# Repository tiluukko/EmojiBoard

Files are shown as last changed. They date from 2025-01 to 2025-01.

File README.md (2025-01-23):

# EmojiBoard
Emojiboard documentation &amp; build kit assets &amp; instructions

    LUX
    Emojiboard
    v2.0
    Luukkonen Timo
    1-22-2025

Device and Program Documentation

OVERVIEW

The hardware setup includes a Raspberry Pi (version 3 B v1.2) connected to:
    
        •	A 3x7 + 2x2 button matrix.
        •	NeoPixel LEDs (26 units).
        •	A buzzer (connected to GPIO pin 16).
        •	The program logs keypresses into a CSV file.

The program is implemented in Python and uses libraries such as RPi.GPIO, rpi_ws281x, and datetime. It starts automatically when the device boots using a cron job and saves keypresses to the file keypress_log.csv         located in the /home/emojikeyboard folder.
 

PROGRAM FUNCTIONALITY

NEOPIXEL LED CONTROL

Each button in the matrix is linked to a specific NeoPixel LED. When a button is pressed, its corresponding NeoPixel lights up green and returns to its default state once the button is released. NeoPixel 10 is programmatically set to remain off at all times and is not used in the program.

BUTTON MATRIX

The matrix is divided into two sections:

    1.	A 3x7 matrix.
    2.	A 2x2 matrix.

The buttons are assigned the following functions:

    •	BACKSPACE: Clears the keypresses in the current session.
    •	RETURN: Saves the current session data and starts a new session.
    •	Other buttons: Add the pressed key to the current session.
    •	Key to Emojis conversion table attached to this document.

KEYPRESS LOGGING

The program logs each session in the following format:

    •	A username (randomly generated combination of an adjective, animal, and unique code).
    •	Keypresses.
    •	A timestamp of when the session is saved.

The data is stored in the file keypress_log.csv.

AUTOMATIC PROGRAM STARTUP

The program is configured to run automatically on device boot using a cron job. Add the following line to the user’s crontab file by running crontab -e:

        @reboot python3 /home/emojikeyboard/keyboard-140.py

INSTRUCTIONS FOR COPYING KEYPRESS_LOG.CSV TO A USB STICK

    1.    Connect HDMI display and a regular keyboard to the Emojiboard.
  	2.    Connect power cable.
    3.    Insert the USB stick into the Raspberry Pi.
    4.    Identify the USB stick’s mount point using the command: 
            lsblk
          
          The stick is typically listed as /dev/sda1.
    
    5.    Mount the USB stick using the command (assuming it is /dev/sda1): 
            sudo mount /dev/sda1 /mnt

    6.    Copy the log file to the USB stick:     
        cp /home/emojikeyboard/keypress_log.csv /mnt

    7.    Safely unmount the USB stick: 
            sudo umount /mnt

    8.    Remove the USB stick from the device.

TROUBLESHOOTING

If the program does not start or the NeoPixel LEDs do not function correctly:

    1.	Verify that all hardware connections are correct.
    2.	Ensure the required libraries are installed: 
        pip3 install rpi_ws281x RPi.GPIO
    3.	Check /home/emojiboard/keyboard_debug.log
    4.	Check /var/log/syslog for error messages.

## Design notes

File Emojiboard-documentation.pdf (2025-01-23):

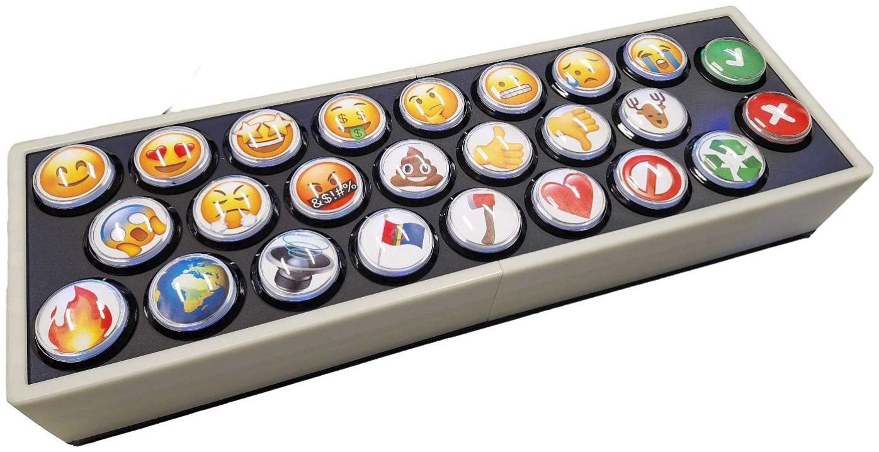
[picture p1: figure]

Timo Luukkonen | 23.1.2025

University of Lapland

User Experience Research Group LUX

# EMOJIBOARD

Standalone feedback collecting keyboard with interchangeable emojis.

Version 2.0

## 1 TABLE OF CONTENTS

### 2 Overview | 2 3 Program Functionality | 3 3.1 NeoPixel LED Control | 3 3.2 Button Matrix | 3 3.3 Keypress Logging | 3 4 Automatic Program Startup | 3 5 Instructions for Copying keypress_log.csv to a USB Stick | 4

### 6 Troubleshooting | 5 7 Attachements | 6 7.1 Logical table & letters to emoji conversion | 6 7.2 Wiring schematic | 0 7.3 Rasperry PI 3b v. 1.2 PINOUT | 1 7.4 Button specifications | 2 7.5 LED String specification | 3 7.6 Build Photos | 4

# Device and Program Documentation

## 2 OVERVIEW

The hardware setup includes a Raspberry Pi (version 3 B v1.2) connected to:

- A 3x7 + 2x2 button matrix.
- NeoPixel LEDs (26 units).
- A buzzer (connected to GPIO pin 16).
- The program logs keypresses into a CSV file.

The program is implemented in Python and uses libraries such as RPi.GPIO, rpi_ws281x, and datetime. It starts automatically when the device boots using a cron job and saves keypresses to the file keypress_log.csv located in the /home/emojikeyboard folder.

## 3 PROGRAM FUNCTIONALITY

### 3.1 NEOPIXEL LED CONTROL

Each button in the matrix is linked to a specific NeoPixel LED. When a button is pressed, its corresponding NeoPixel lights up green and returns to its default state once the button is released. NeoPixel 10 is programmatically set to remain off at all times and is not used in the program.

### 3.2 BUTTON MATRIX

The matrix is divided into two sections:

1. A 3x7 matrix.
2. A 2x2 matrix.

The buttons are assigned the following functions:

- BACKSPACE: Clears the keypresses in the current session.
- RETURN: Saves the current session data and starts a new session.
- Other buttons: Add the pressed key to the current session.
- Key to Emojis conversion table attached to this document.

### 3.3 KEYPRESS LOGGING

The program logs each session in the following format:

- A username (randomly generated combination of an adjective, animal, and unique code).
- Keypresses.
- A timestamp of when the session is saved.

The data is stored in the file keypress_log.csv.

## 4 AUTOMATIC PROGRAM STARTUP

The program is configured to run automatically on device boot using a cron job. Add the following line to the user’s crontab file by running crontab -e:

@reboot python3 /home/emojikeyboard/keyboard-140.py

## 5 INSTRUCTIONS FOR COPYING KEYPRESS_LOG.CSV TO A USB STICK

1. Connect HDMI display and a regular keyboard to the Emojiboard.
2. Connect power cable.
3. Insert the USB stick into the Raspberry Pi.

### 4. Identify the USB stick’s mount point using the command:

lsblk

The stick is typically listed as /dev/sda1.

### 5. Mount the USB stick using the command (assuming it is /dev/sda1):

sudo mount /dev/sda1 /mnt

### 6. Copy the log file to the USB stick:

cp /home/emojikeyboard/keypress_log.csv /mnt

### 7. Safely unmount the USB stick:

sudo umount /mnt

8. Remove the USB stick from the device.

## 6 TROUBLESHOOTING

If the program does not start or the NeoPixel LEDs do not function correctly:

1. Verify that all hardware connections are correct.

### 2. Ensure the required libraries are installed:

pip3 install rpi_ws281x RPi.GPIO

### 3. Check /home/emojiboard/keyboard_debug.log

4. Check /var/log/syslog for error messages.

## 7 ATTACHEMENTS

### 7.1 LOGICAL TABLE & LETTERS TO EMOJI CONVERSION

Button Number | Button Label | Key Mapped | NeoPixel Number | Matrix | Row | Column | Emoji
1 | A | 'A' | 1 | 3x7 | 1 | 1
2 | B | 'B' | 2 | 3x7 | 1 | 2
3 | C | 'C' | 3 | 3x7 | 1 | 3
4 | D | 'D' | 4 | 3x7 | 1 | 4
5 | E | 'E' | 5 | 3x7 | 1 | 5
6 | F | 'F' | 6 | 3x7 | 1 | 6
7 | G | 'G' | 7 | 3x7 | 1 | 7
8 | H | 'H' | 17 | 3x7 | 2 | 1
9 | I | 'I' | 16 | 3x7 | 2 | 2
10 | J | 'J' | 15 | 3x7 | 2 | 3
11 | K | 'K' | 14 | 3x7 | 2 | 4
12 | L | 'L' | 13 | 3x7 | 2 | 5
13 | M | 'M' | 12 | 3x7 | 2 | 6
14 | N | 'N' | 11 | 3x7 | 2 | 7
15 | O | 'O' | 18 | 3x7 | 3 | 1
16 | P | 'P' | 19 | 3x7 | 3 | 2
17 | Q | 'Q' | 20 | 3x7 | 3 | 3
18 | R | 'R' | 21 | 3x7 | 3 | 4
19 | S | 'S' | 22 | 3x7 | 3 | 5
20 | T | 'T' | 23 | 3x7 | 3 | 6
21 | U | 'U' | 24 | 3x7 | 3 | 7
22 | V | 'V' | 8 | 2x2 | 1 | 1
23 | Enter | KEY_RETURN | 9 | 2x2 | 1 | 2
24 | X | 'X' | 25 | 2x2 | 2 | 1
25 | Backspace | KEY_BACKSPACE | 26 | 2x2 | 2 | 2

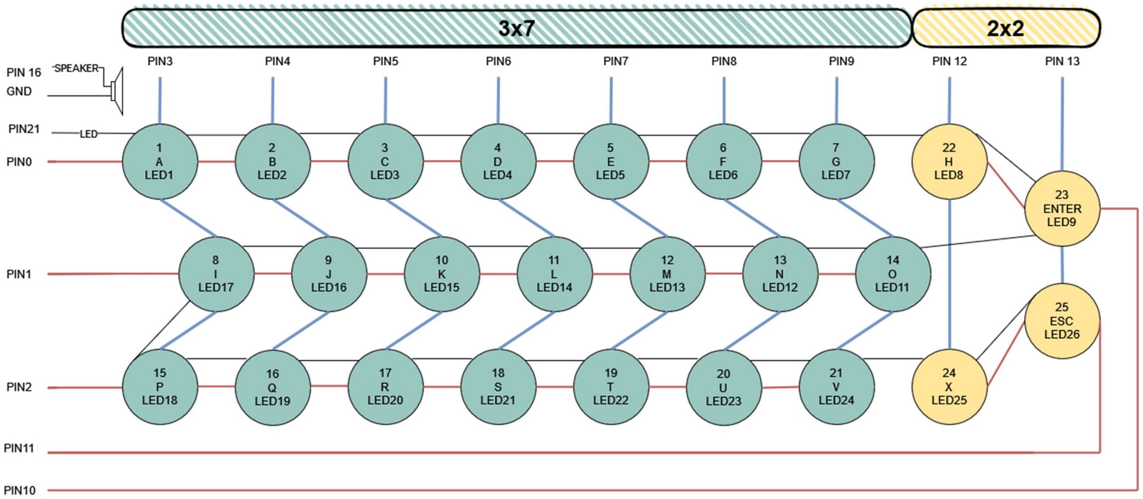
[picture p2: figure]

Timo Luukkonen | 23.1.2025

University of Lapland

User Experience Research Group LUX

### 7.2 WIRING SCHEMATIC

## 7.3 RASPERRY PI 3B V. 1.2 PINOUT

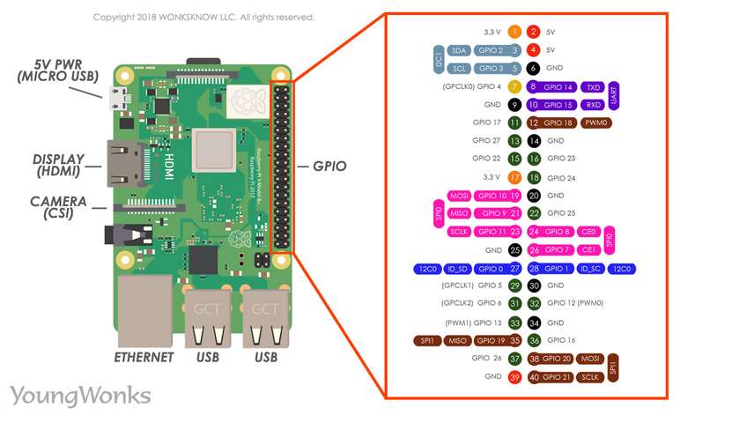
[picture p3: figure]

### 7.4 BUTTON SPECIFICATIONS

60mm LED Illuminated Push Button Switch Arcade DC5V/12V

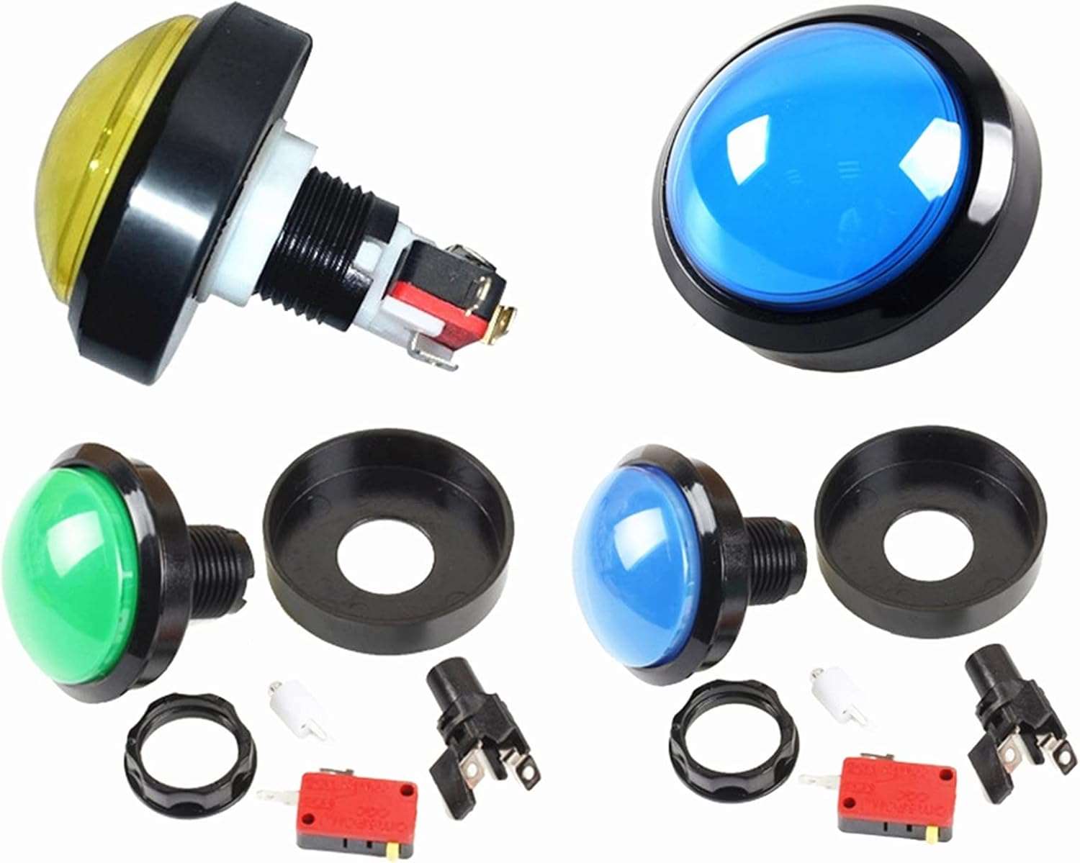
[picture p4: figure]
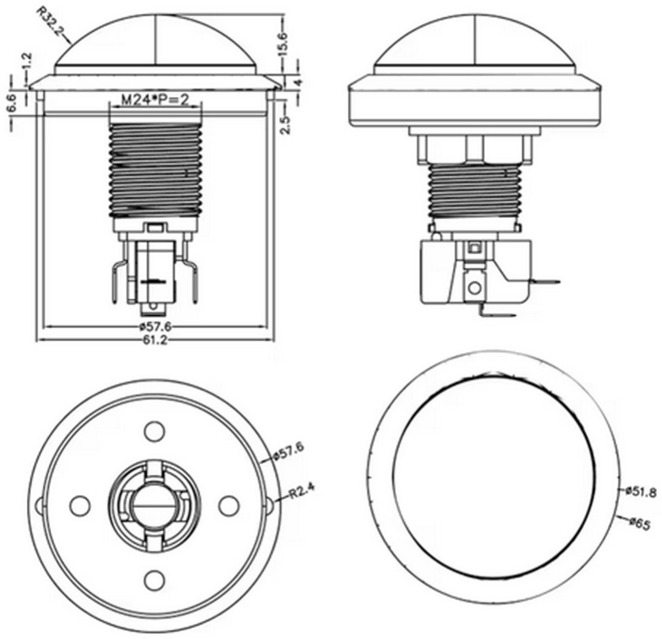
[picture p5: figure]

### 7.5 LED STRING SPECIFICATION

Dc5v Ws2811 Full Color Led Pixel Light Module 12mm

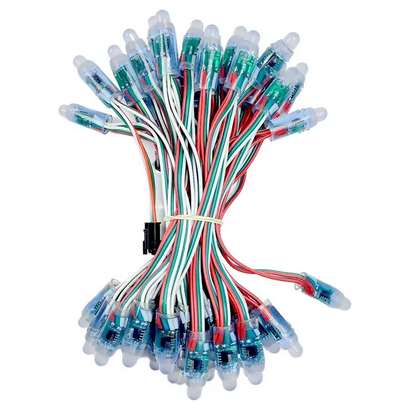
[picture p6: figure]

### 7.6 BUILD PHOTOS

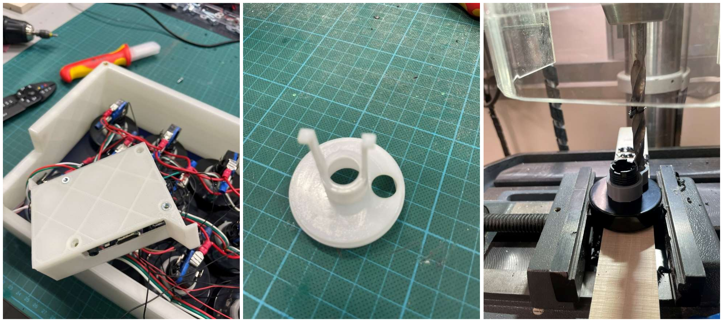
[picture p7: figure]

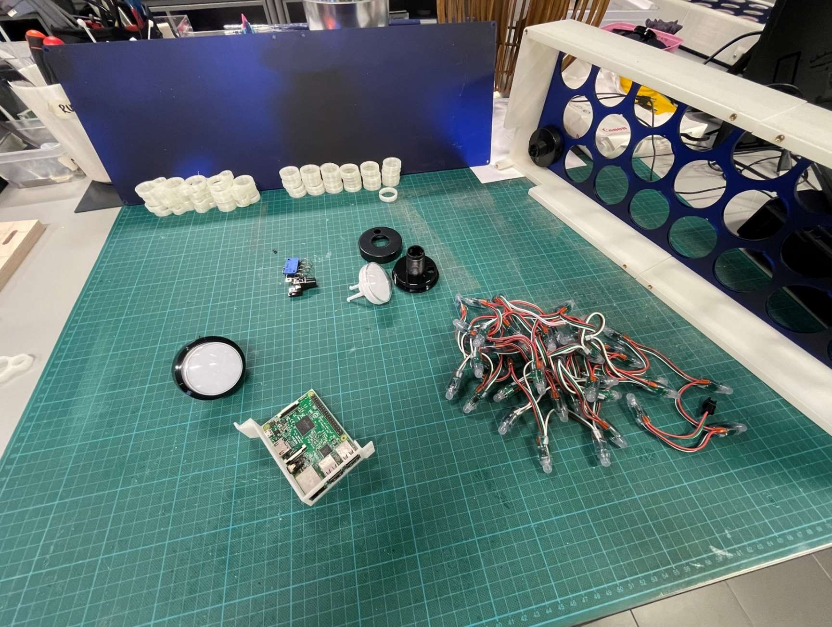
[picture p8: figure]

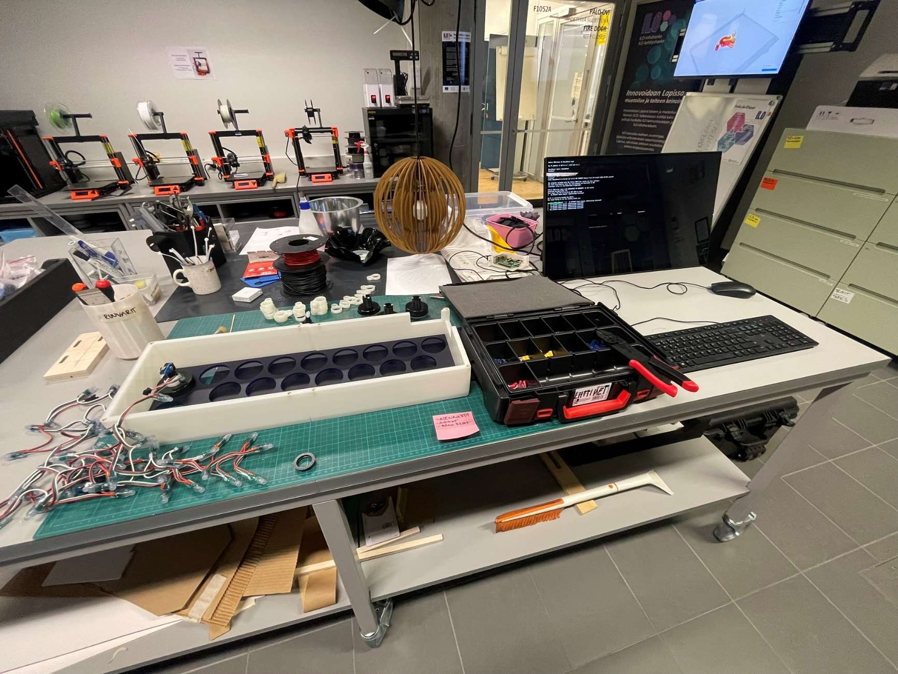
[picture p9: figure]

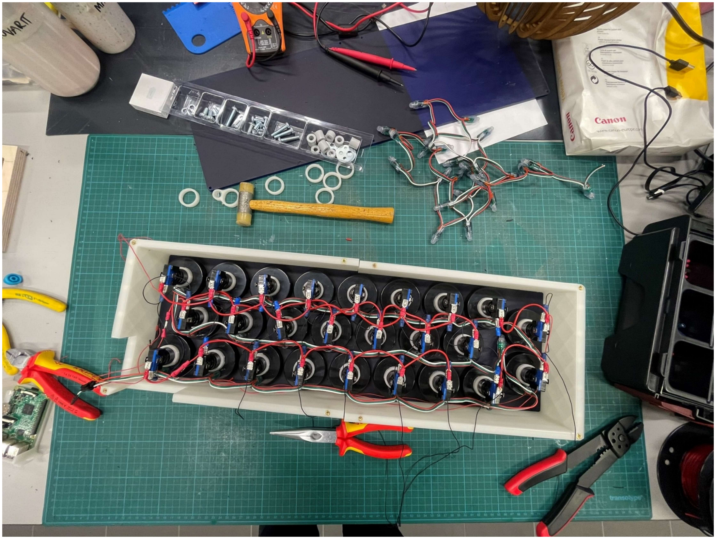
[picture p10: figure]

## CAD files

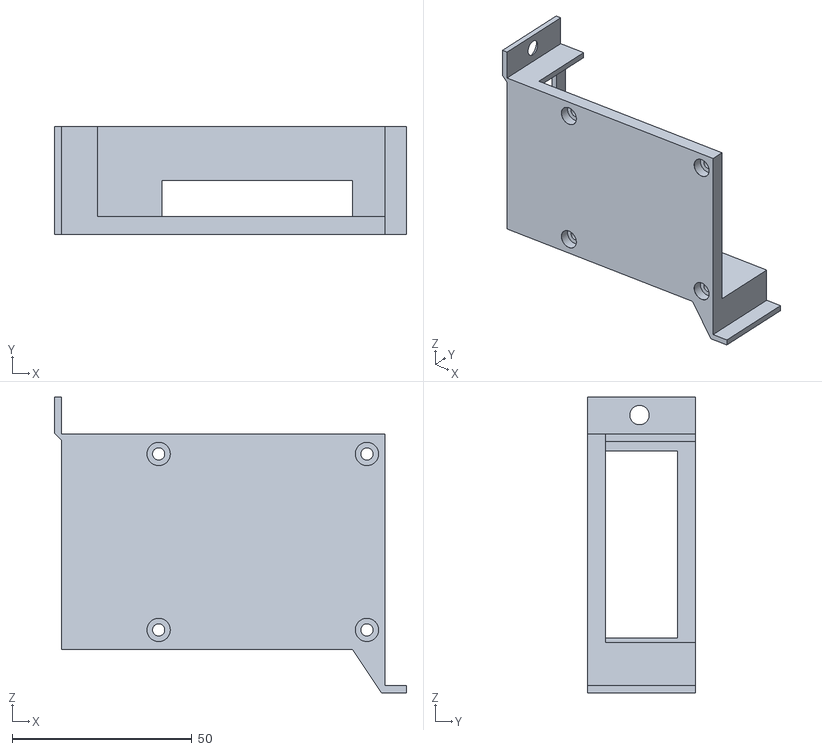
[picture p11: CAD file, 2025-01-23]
RPI-slot.STL
98.0 x 30.0 x 82.3

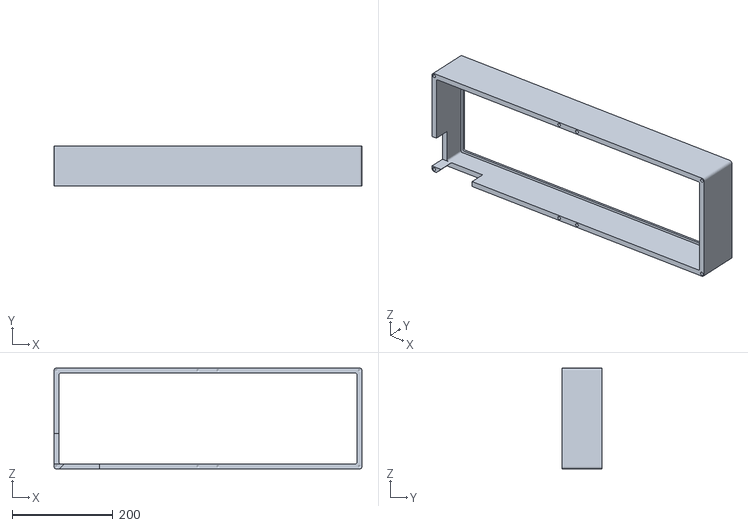
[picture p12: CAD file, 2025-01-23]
Casing.STL
610.0 x 80.0 x 200.0

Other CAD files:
BasePlate.dwg
Faceplate.DWG

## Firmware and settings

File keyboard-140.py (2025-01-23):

# Version 1.4.0 (Raspberry Pi)
import RPi.GPIO as GPIO
import time
import random
import string
from datetime import datetime
from rpi_ws281x import PixelStrip, Color, WS2811_STRIP_RGB
import logging

# Set up logging
logging.basicConfig(
    filename='keyboard_debug.log',
    level=logging.DEBUG,
    format='%(asctime)s - %(levelname)s - %(message)s'
)

# GPIO pin assignments
ROW_PINS = [0, 1, 2]
COL_PINS = [3, 4, 5, 6, 7, 8, 9]
EXTRA_ROW_PINS = [10, 11]
EXTRA_COL_PINS = [12, 13]
SPEAKER_PIN = 16
NEO_PIN = 21
NUM_PIXELS = 26

# Colors - Explicitly define RGB values for WS2811
RED = Color(255, 0, 0)      # Pure red
GREEN = Color(0, 255, 0)    # Pure green
BLUE = Color(0, 0, 255)     # Pure blue
WHITE = Color(255, 255, 255)  # White

# Define colors for different states
SELECTED_COLOR = GREEN
RETURN_COLOR = GREEN
BACKSPACE_COLOR = RED
DEFAULT_COLOR = WHITE

# Button and key mappings (same as before)
BUTTON_MAP_3x7 = [
    [1, 2, 3, 4, 5, 6, 7],
    [8, 9, 10, 11, 12, 13, 14],
    [15, 16, 17, 18, 19, 20, 21]
]
BUTTON_MAP_2x2 = [
    [22, 23],
    [24, 25]
]

PIXEL_MAP_3x7 = [
    [1, 2, 3, 4, 5, 6, 7],
    [17, 16, 15, 14, 13, 12, 11],
    [18, 19, 20, 21, 22, 23, 24]
]
PIXEL_MAP_2x2 = [
    [8, 9],
    [25, 26]
]

KEY_MAP_3x7 = [
    ["A", "B", "C", "D", "E", "F", "G"],
    ["I", "J", "K", "L", "M", "N", "O"],
    ["P", "Q", "R", "S", "T", "U", "V"]
]
KEY_MAP_2x2 = [
    ["H", "RETURN"],
    ["X", "BACKSPACE"]
]

class KeyboardRecorder:
    def __init__(self):
        self.current_session_keys = []
        self.selected_keys = set()
        self.current_user_id = self.generate_user_id()
        self.strip = None
        self.setup_neopixels()
        self.setup_audio()
        self.last_keypress_time = 0
        self.debounce_delay = 0.2
        self.matrix_state = [[False for _ in COL_PINS] for _ in ROW_PINS]
        self.extra_matrix_state = [[False for _ in EXTRA_COL_PINS] for _ in EXTRA_ROW_PINS]
        
    def setup_audio(self):
        """Initialize PWM for the speaker"""
        try:
            self.pwm = GPIO.PWM(SPEAKER_PIN, 440)  # Start with 440 Hz (A4 note)
            self.pwm.start(0)  # Start with 0% duty cycle (silent)
            logging.info("Audio PWM initialized successfully")
        except Exception as e:
            logging.error(f"Failed to initialize audio PWM: {e}")
            raise

    def play_key_beep(self):
        """Play a short beep for regular key presses"""
        try:
            self.pwm.ChangeFrequency(440)  # A4 note
            self.pwm.ChangeDutyCycle(50)
            time.sleep(0.05)  # Short duration
            self.pwm.ChangeDutyCycle(0)
        except Exception as e:
            logging.error(f"Error playing key beep: {e}")

    def play_success_sound(self):
        """Play a success melody when Return is pressed"""
        try:
            # Play an ascending arpeggio
            notes = [
                (392, 0.1),  # G4
                (493.88, 0.1),  # B4
                (587.33, 0.1),  # D5
                (783.99, 0.2)   # G5
            ]
            
            for freq, duration in notes:
                self.pwm.ChangeFrequency(freq)
                self.pwm.ChangeDutyCycle(50)
                time.sleep(duration)
                
            self.pwm.ChangeDutyCycle(0)
        except Exception as e:
            logging.error(f"Error playing success sound: {e}")

    def setup_neopixels(self):
        try:
            # Initialize with explicit WS2811 RGB strip type
            self.strip = PixelStrip(NUM_PIXELS, NEO_PIN, strip_type=WS2811_STRIP_RGB)
            self.strip.begin()
            self.set_default_colors()
            logging.info("NeoPixels initialized successfully")
        except Exception as e:
            logging.error(f"Failed to initialize NeoPixels: {e}")
            raise
            
    def set_default_colors(self):
        """Set all LEDs to their default states"""
        for i in range(NUM_PIXELS):
            self.strip.setPixelColor(i, WHITE_COLOR)
        
        return_pixel = self.find_pixel_index("RETURN")
        backspace_pixel = self.find_pixel_index("BACKSPACE")
        if return_pixel >= 0:
            self.strip.setPixelColor(return_pixel, GREEN_COLOR)
        if backspace_pixel >= 0:
            self.strip.setPixelColor(backspace_pixel, RED_COLOR)
        
        self.strip.show()

    def generate_user_id(self):
        adjectives = ["Quick", "Happy", "Bright", "Calm", "Sharp", "Brave", "Smart", "Kind", "Loyal", "Wise"]
        animals = ["Fox", "Bear", "Wolf", "Eagle", "Tiger", "Lion", "Deer", "Owl", "Hawk", "Shark"]
        return f"{random.choice(adjectives)}{random.choice(animals)}{random.randint(1000,9999)}"

    def toggle_key(self, key):
        """Toggle a key's selected state"""
        pixel_index = self.find_pixel_index(key)
        if pixel_index >= 0:
            if key in self.selected_keys:
                self.selected_keys.remove(key)
                self.strip.setPixelColor(pixel_index, WHITE_COLOR)
            else:
                self.selected_keys.add(key)
                self.strip.setPixelColor(pixel_index, GREEN_COLOR)
            self.strip.show()

    def handle_keypress(self, key):
        current_time = time.time()
        
        if current_time - self.last_keypress_time < self.debounce_delay:
            return
            
        self.last_keypress_time = current_time
        logging.debug(f"Key pressed: {key}")

        if key == "BACKSPACE":
            self.play_key_beep()
            self.selected_keys.clear()
            self.set_default_colors()
        elif key == "RETURN":
            if self.selected_keys:  # Only play success sound if there are selected keys
                self.play_success_sound()
            self.current_session_keys = list(self.selected_keys)
            self.save_session()
            self.selected_keys.clear()
            self.current_session_keys = []
            self.current_user_id = self.generate_user_id()
            self.set_default_colors()
        else:
            self.play_key_beep()
            self.toggle_key(key)

    def find_pixel_index(self, key):
        for row_idx, row in enumerate(KEY_MAP_3x7):
            if key in row:
                col_idx = row.index(key)
                return PIXEL_MAP_3x7[row_idx][col_idx] - 1
        for row_idx, row in enumerate(KEY_MAP_2x2):
            if key in row:
                col_idx = row.index(key)
                return PIXEL_MAP_2x2[row_idx][col_idx] - 1
        return -1

    def save_session(self):
        try:
            if self.selected_keys:
                timestamp = datetime.now().strftime("%Y-%m-%d %H:%M:%S")
                session_data = f"{self.current_user_id},{''.join(sorted(self.selected_keys))},{timestamp}\n"
                
                with open("keypress_log.csv", "a") as log_file:
                    log_file.write(session_data)
                logging.info(f"Session saved: {session_data.strip()}")
        except Exception as e:
            logging.error(f"Error saving session: {e}")

    def scan_matrix(self):
        current_time = time.time()
        if (current_time - self.last_keypress_time) < self.debounce_delay:
            return

        # Reset all row pins to HIGH
        for pin in ROW_PINS + EXTRA_ROW_PINS:
            GPIO.output(pin, GPIO.HIGH)

        key_detected = False
        
        # Scan main matrix (3x7)
        for row_idx, row_pin in enumerate(ROW_PINS):
            # Set current row LOW
            GPIO.output(row_pin, GPIO.LOW)
            time.sleep(0.001)  # Allow signal to settle
            
            # Read all columns for this row
            for col_idx, col_pin in enumerate(COL_PINS):
                is_pressed = GPIO.input(col_pin) == GPIO.LOW
                
                # If this is a new keypress
                if is_pressed and not self.matrix_state[row_idx][col_idx]:
                    key = KEY_MAP_3x7[row_idx][col_idx]
                    self.handle_keypress(key)
                    key_detected = True
                    self.last_keypress_time = current_time
                
                # Update state
                self.matrix_state[row_idx][col_idx] = is_pressed
            
            # Set row back to HIGH
            GPIO.output(row_pin, GPIO.HIGH)
            
            if key_detected:
                return

        # Scan extra matrix (2x2) only if no key was detected in main matrix
        if not key_detected:
            for row_idx, row_pin in enumerate(EXTRA_ROW_PINS):
                GPIO.output(row_pin, GPIO.LOW)
                time.sleep(0.001)
                
                for col_idx, col_pin in enumerate(EXTRA_COL_PINS):
                    is_pressed = GPIO.input(col_pin) == GPIO.LOW
                    
                    if is_pressed and not self.extra_matrix_state[row_idx][col_idx]:
                        key = KEY_MAP_2x2[row_idx][col_idx]
                        self.handle_keypress(key)
                        self.last_keypress_time = current_time
                    
                    self.extra_matrix_state[row_idx][col_idx] = is_pressed
                
                GPIO.output(row_pin, GPIO.HIGH)

        time.sleep(0.001)  # Small delay at the end of scanning

    def set_default_colors(self):
        """Set all LEDs to their default states"""
        for i in range(NUM_PIXELS):
            self.strip.setPixelColor(i, DEFAULT_COLOR)
        
        return_pixel = self.find_pixel_index("RETURN")
        backspace_pixel = self.find_pixel_index("BACKSPACE")
        if return_pixel >= 0:
            self.strip.setPixelColor(return_pixel, RETURN_COLOR)
        if backspace_pixel >= 0:
            self.strip.setPixelColor(backspace_pixel, BACKSPACE_COLOR)
        
        self.strip.show()

    def toggle_key(self, key):
        """Toggle a key's selected state"""
        pixel_index = self.find_pixel_index(key)
        if pixel_index >= 0:
            if key in self.selected_keys:
                self.selected_keys.remove(key)
                self.strip.setPixelColor(pixel_index, DEFAULT_COLOR)
                logging.debug(f"Key {key} deselected, pixel {pixel_index} set to DEFAULT")
            else:
                self.selected_keys.add(key)
                self.strip.setPixelColor(pixel_index, SELECTED_COLOR)
                logging.debug(f"Key {key} selected, pixel {pixel_index} set to SELECTED")
            self.strip.show()

def handle_keypress(self, key):
        current_time = time.time()
        
        if current_time - self.last_keypress_time < self.debounce_delay:
            return
            
        self.last_keypress_time = current_time
        logging.debug(f"Key pressed: {key}")

        if key == "BACKSPACE":
            self.play_key_beep()
            self.selected_keys.clear()
            self.set_default_colors()
        elif key == "RETURN":
            if self.selected_keys:  # Only play success sound if there are selected keys
                self.play_success_sound()
            self.current_session_keys = list(self.selected_keys)
            self.save_session()
            self.selected_keys.clear()
            self.current_session_keys = []
            self.current_user_id = self.generate_user_id()
            self.set_default_colors()
        else:
            self.play_key_beep()
            self.toggle_key(key)

def find_pixel_index(self, key):
        for row_idx, row in enumerate(KEY_MAP_3x7):
            if key in row:
                col_idx = row.index(key)
                return PIXEL_MAP_3x7[row_idx][col_idx] - 1
        for row_idx, row in enumerate(KEY_MAP_2x2):
            if key in row:
                col_idx = row.index(key)
                return PIXEL_MAP_2x2[row_idx][col_idx] - 1
        return -1

def save_session(self):
        try:
            if self.selected_keys:
                timestamp = datetime.now().strftime("%Y-%m-%d %H:%M:%S")
                session_data = f"{self.current_user_id},{''.join(sorted(self.selected_keys))},{timestamp}\n"
                
                with open("keypress_log.csv", "a") as log_file:
                    log_file.write(session_data)
                logging.info(f"Session saved: {session_data.strip()}")
        except Exception as e:
            logging.error(f"Error saving session: {e}")

def scan_matrix(self):
        # Reset current pressed key if enough time has passed (key release)
        if (time.time() - self.last_keypress_time) > self.debounce_delay:
            self.current_pressed_key = None

        # Only scan if no key is currently being pressed
        if self.current_pressed_key is None:
            # Scan 3x7 matrix
            for row in range(len(ROW_PINS)):
                GPIO.output(ROW_PINS[row], GPIO.LOW)
                time.sleep(0.001)  # Small delay to stabilize
                
                for col in range(len(COL_PINS)):
                    if GPIO.input(COL_PINS[col]) == GPIO.LOW:
                        key = KEY_MAP_3x7[row][col]
                        if self.current_pressed_key is None:  # Only register if no other key is pressed
                            self.current_pressed_key = key
                            self.handle_keypress(key)
                            self.last_keypress_time = time.time()
                            break  # Exit after first key detection
                
                GPIO.output(ROW_PINS[row], GPIO.HIGH)
                
                if self.current_pressed_key:  # If we found a key, stop scanning
                    break

            # Only scan 2x2 matrix if no key was found in 3x7 matrix
            if not self.current_pressed_key:
                for row in range(len(EXTRA_ROW_PINS)):
                    GPIO.output(EXTRA_ROW_PINS[row], GPIO.LOW)
                    time.sleep(0.001)
                    
                    for col in range(len(EXTRA_COL_PINS)):
                        if GPIO.input(EXTRA_COL_PINS[col]) == GPIO.LOW:
                            key = KEY_MAP_2x2[row][col]
                            if self.current_pressed_key is None:
                                self.current_pressed_key = key
                                self.handle_keypress(key)
                                self.last_keypress_time = time.time()
                                break
                    
                    GPIO.output(EXTRA_ROW_PINS[row], GPIO.HIGH)
                    
                    if self.current_pressed_key:
                        break

        # Add a small delay to prevent CPU overload
        time.sleep(0.01)
		
def setup_gpio():
    try:
        GPIO.setmode(GPIO.BCM)
        GPIO.setwarnings(False)  # Disable warnings
        
        # Setup row pins as outputs
        for pin in ROW_PINS + EXTRA_ROW_PINS:
            GPIO.setup(pin, GPIO.OUT, initial=GPIO.HIGH)
            
        # Setup column pins as inputs with pull-up resistors
        for pin in COL_PINS + EXTRA_COL_PINS:
            GPIO.setup(pin, GPIO.IN, pull_up_down=GPIO.PUD_UP)
            
        GPIO.setup(SPEAKER_PIN, GPIO.OUT)
        logging.info("GPIO setup completed successfully")
    except Exception as e:
        logging.error(f"GPIO setup failed: {e}")
        raise
		
def main():
    try:
        setup_gpio()
        keyboard = KeyboardRecorder()
        logging.info("Keyboard recorder initialized and running...")
        
        while True:
            keyboard.scan_matrix()
            time.sleep(0.01)
            
    except KeyboardInterrupt:
        logging.info("Program terminated by user")
    except Exception as e:
        logging.error(f"Unexpected error: {e}")
    finally:
        if hasattr(keyboard, 'pwm'):
            keyboard.pwm.stop()
        GPIO.cleanup()
        logging.info("GPIO cleanup completed")

if __name__ == "__main__":
    main()
